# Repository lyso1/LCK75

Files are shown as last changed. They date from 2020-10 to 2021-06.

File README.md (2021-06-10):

# LCK75

a 75% through-hole keyboard designed by myself with inspiration from the CFTKB Discipline and Yiancar Gingham

LCK75-Mainboard

LCK75-Plate

LCK75-Bottom

<br />This work is licensed under a <a rel="license" href="http://creativecommons.org/licenses/by/4.0/">Creative Commons Attribution 4.0 International License</a>.

i will not be held responsible for your endeavors with private runs of this board. 

if you have questions reach out to me on discord @Lysol#5640

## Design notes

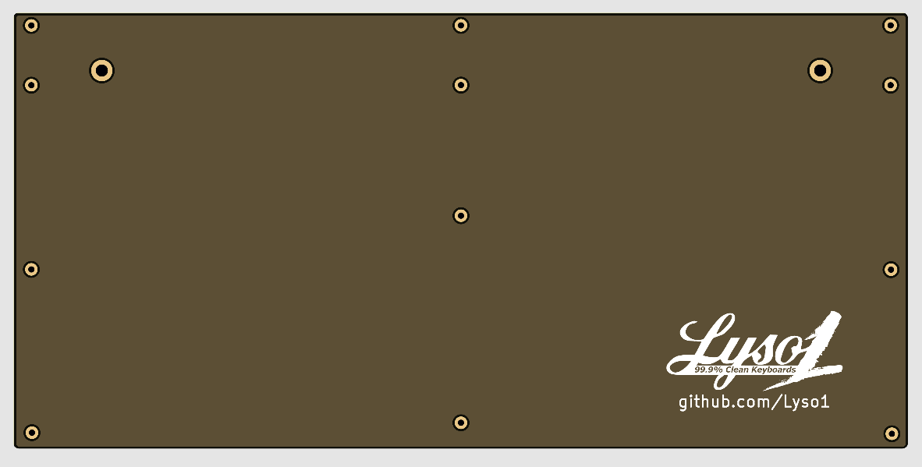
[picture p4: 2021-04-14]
LCK75 images/lck pcb designs - Imgur (2).png

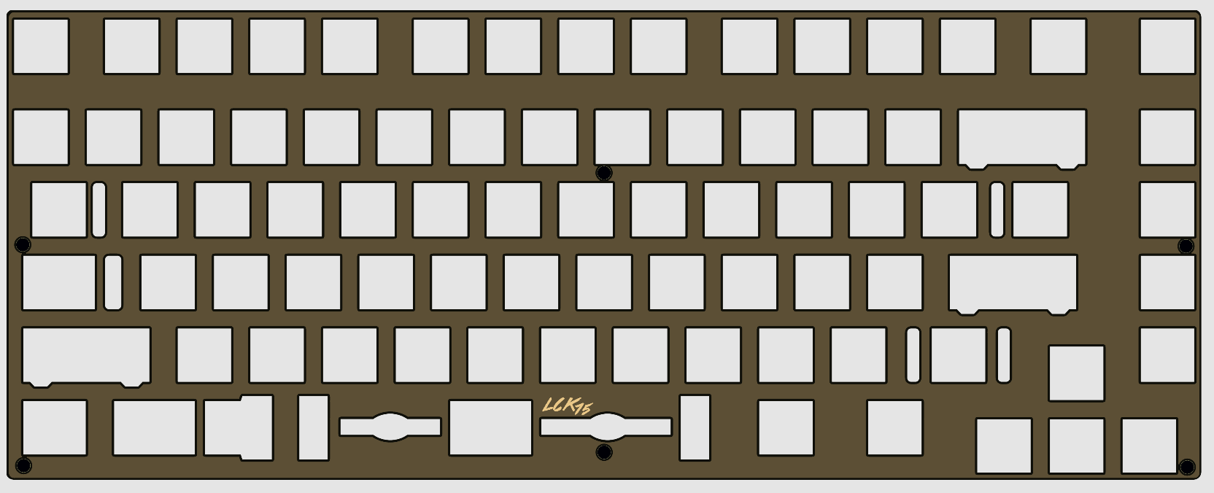
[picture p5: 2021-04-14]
LCK75 images/lck pcb designs - Imgur.png

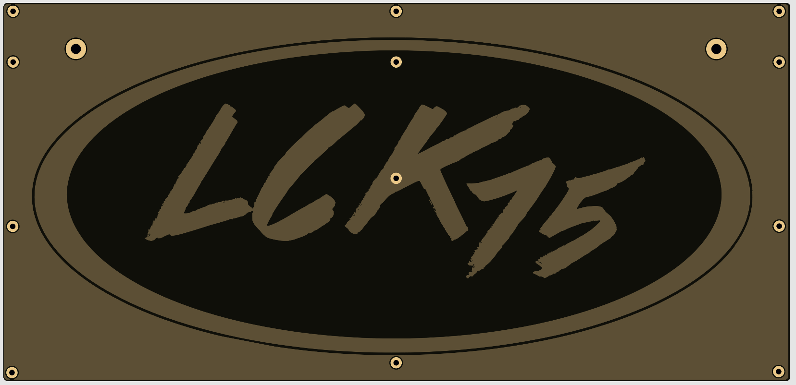
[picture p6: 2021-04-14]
LCK75 images/lck pcb designs - Imgur (1).png

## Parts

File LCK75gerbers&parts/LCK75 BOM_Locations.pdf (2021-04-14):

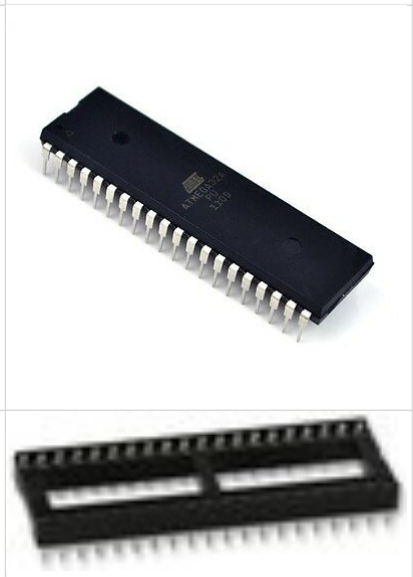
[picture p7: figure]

Location | Component
U1 | ATMEGA32A-PU

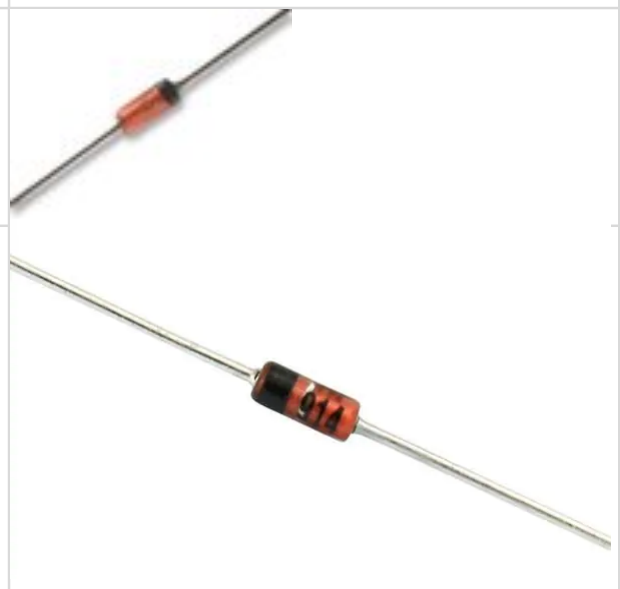
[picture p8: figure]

U1 | IC Socket
D1-D82 | through hole diodes/ 512-1N4148TR
Z1,Z2 | 3.6v Zener diodes

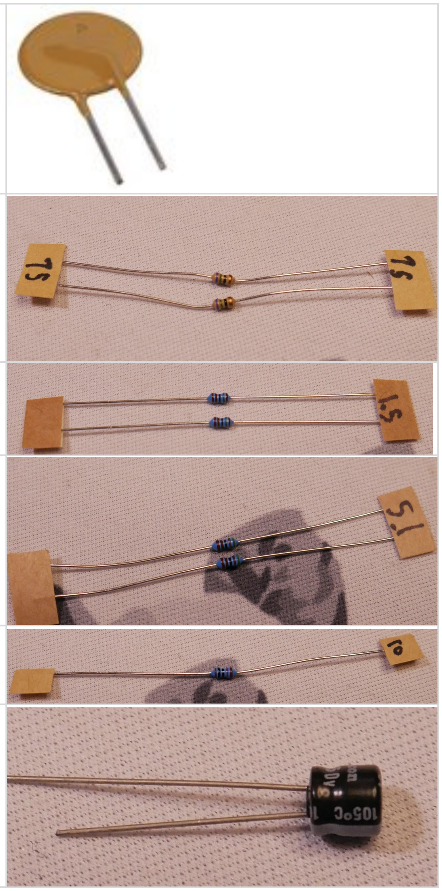
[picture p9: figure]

FUSE | 500mA fuse
R3,R4 | 75 ohm resistor
R1,R7 | 1.5k ohm resistor
R2,R5 | 5.1k ohm resistor
R6 | 10k ohm resistor
4.7uF | 4.7uF cylindrical capacitor

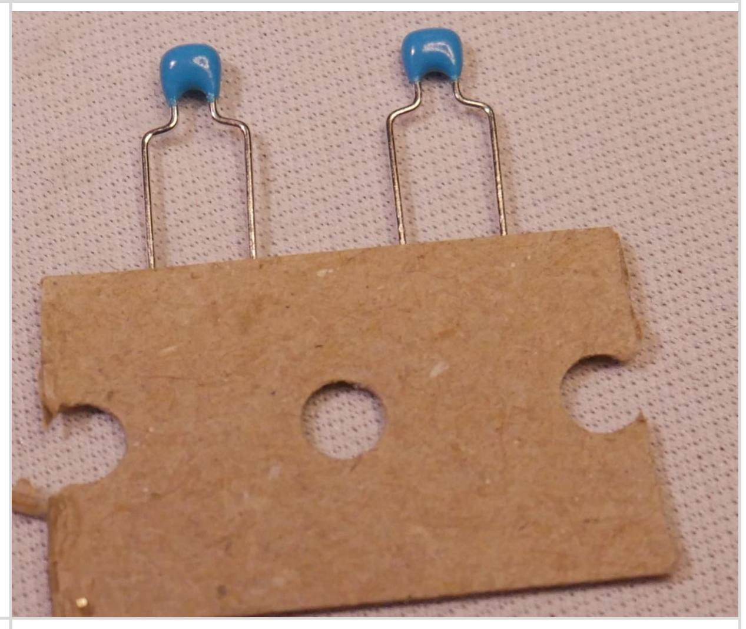
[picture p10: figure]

0.1uF | capacitors that go next to the microcontroller

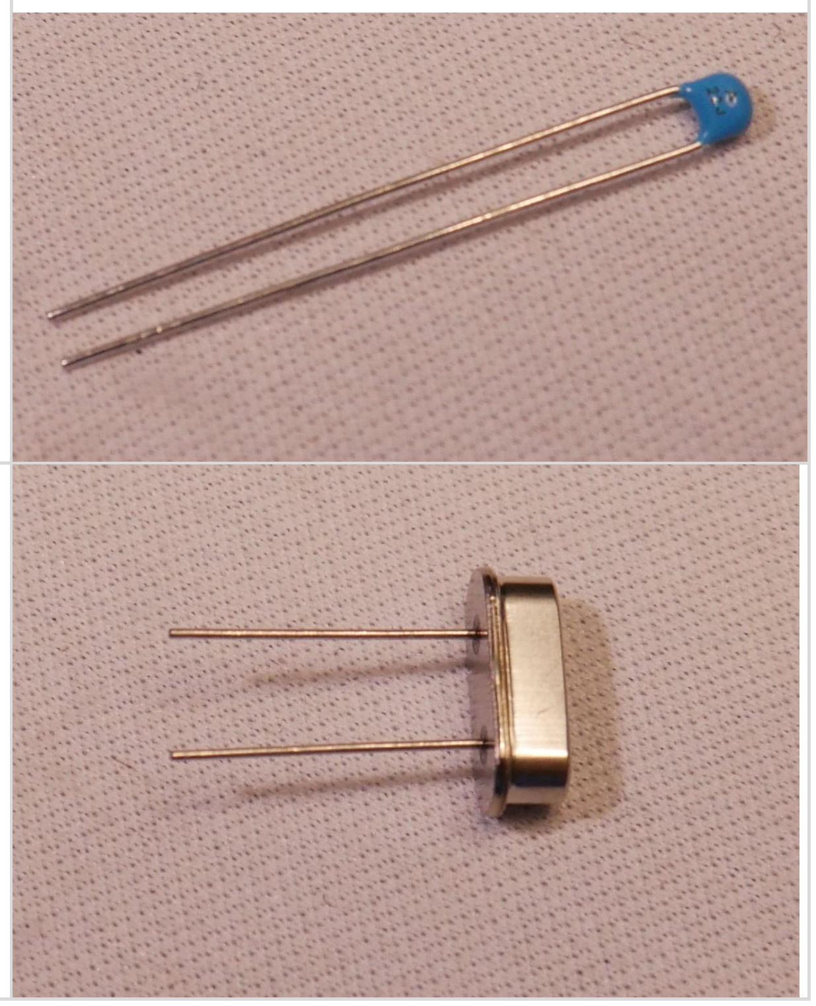
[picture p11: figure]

22pF | capacitors that goes between the crystal on the mainboard
Y1 | Crystal

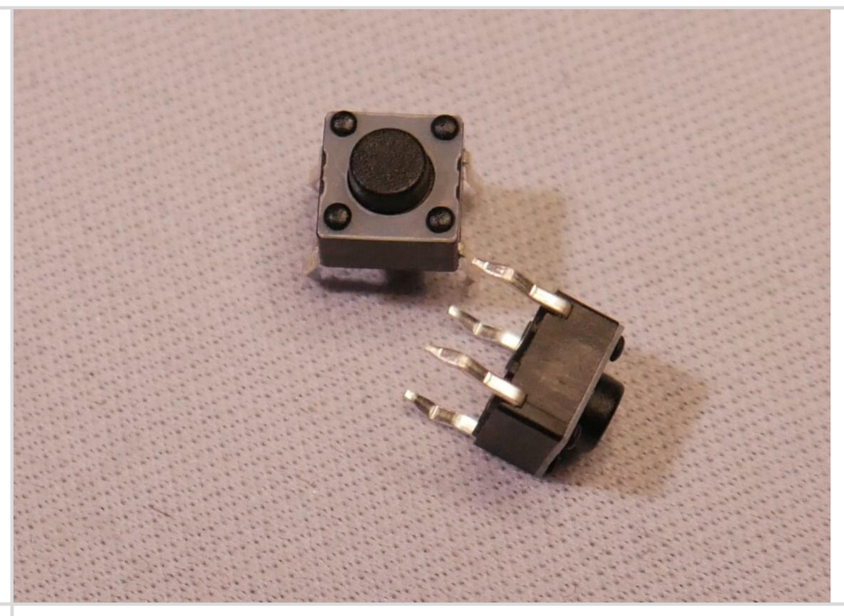
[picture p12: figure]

BOOT,RESET | 6mm push button
SW93 | Rotary Encoder
SSD1306 | OLED Screen
LED | LED
USB1 | USB C Connector

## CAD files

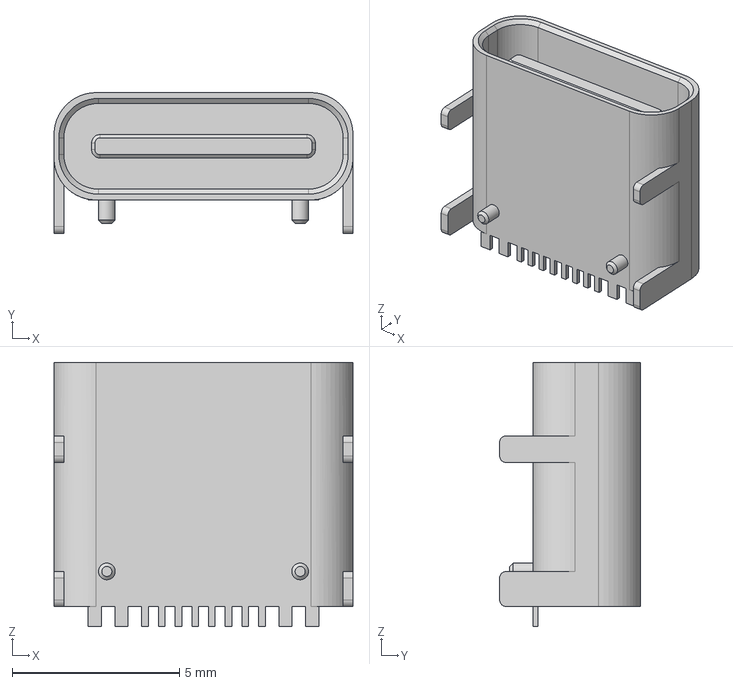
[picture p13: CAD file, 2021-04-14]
LCK75 kicad libs/Type-C.pretty-master/Type-C.pretty-master/HRO TYPE-C-31-M-12.step
8.94 x 4.21 x 7.90 mm

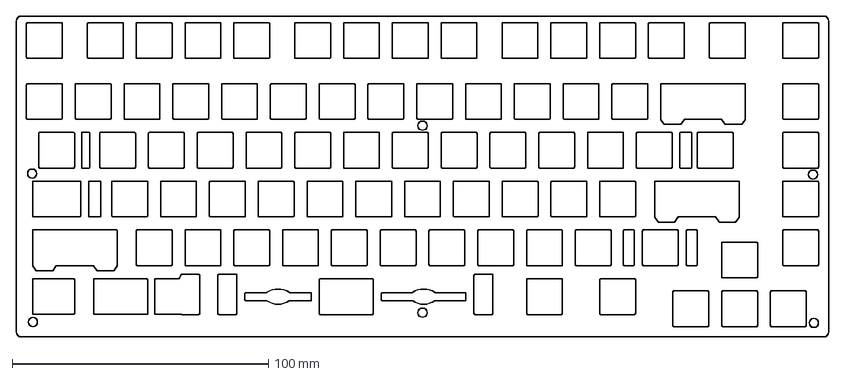
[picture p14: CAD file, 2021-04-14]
LCK75gerbers&parts/LCK75PLATE/LCK75-KITPLATErev1.dxf
317.3 x 125.3 mm

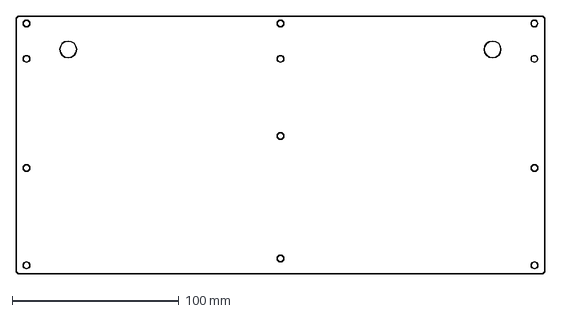
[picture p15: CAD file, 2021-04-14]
LCK75gerbers&parts/LCKFOAM&GUARD/LCKFOAM.dxf
317.3 x 154.8 mm

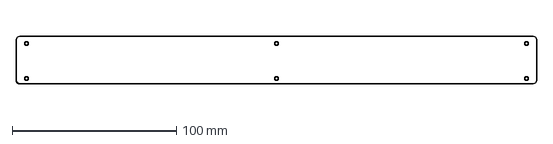
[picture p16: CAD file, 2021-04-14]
LCK75gerbers&parts/LCKFOAM&GUARD/LCK75-acrylic-guard.dxf
317.2 x 28.9 mm

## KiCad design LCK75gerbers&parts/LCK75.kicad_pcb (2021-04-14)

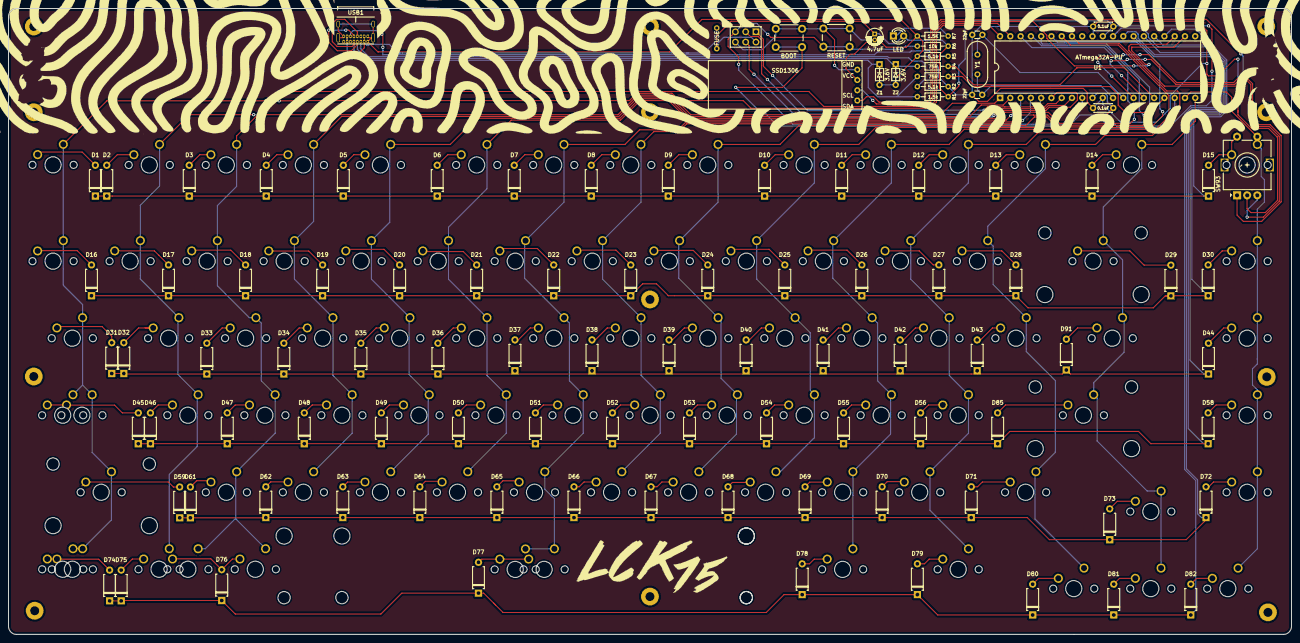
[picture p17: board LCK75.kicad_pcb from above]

Board: 2 copper layers, 317.3 x 154.8 mm, 192 parts (1 on the bottom side), 124 nets.

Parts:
C1, C2: 22pF; C_Disc_D3.0mm_W1.6mm_P2.50mm
C3: 4.7uF; CP_Radial_D4.0mm_P1.50mm
C4, C5: 0.1uF; C_Disc_D4.3mm_W1.9mm_P5.00mm
D1, D2, D3, D4, D5, D6, D7, D8, D9, D10, D11, D12, D13, D14, D15, D16, D17, D18, D19, D20, D21, D22, D23, D24, D25, D26, D27, D28, D29, D30, D31, D32, D33, D34, D35, D36, D37, D38, D39, D40, D41, D42, D43, D44, D45, D46, D47, D48, D49, D50, D51, D52, D53, D54, D55, D56, D58, D59, D61, D62, D63, D64, D65, D66, D67, D68, D69, D70, D71, D72, D73, D74, D75, D76, D77, D78, D79, D80, D81, D82, D85, D91: 1N4148; D_A-405_P7.62mm_Horizontal
F1: 500mA; polyfuse_5.1mm
J1: AVR-ISP-6; AVR_ICSP_3x2
LED: POWER; LED_D3.0mm
R1: 1.5k; R_Axial_DIN0204_L3.6mm_D1.6mm_P7.62mm_Horizontal
R2, R5: 5.1k; R_Axial_DIN0204_L3.6mm_D1.6mm_P7.62mm_Horizontal
R3, R4: 75R; R_Axial_DIN0204_L3.6mm_D1.6mm_P7.62mm_Horizontal
R6: 10k; R_Axial_DIN0204_L3.6mm_D1.6mm_P7.62mm_Horizontal
R7: 1.5K; R_Axial_DIN0204_L3.6mm_D1.6mm_P7.62mm_Horizontal
SSD1306: OLED; ssd1306 128x32 oled
SW1, SW2, SW3, SW4, SW5, SW6, SW7, SW8, SW9, SW10, SW11, SW12, SW13, SW14, SW15, SW16, SW17, SW18, SW19, SW20, SW21, SW22, SW23, SW24, SW25, SW26, SW27, SW28, SW30, SW32, SW33, SW34, SW35, SW36, SW37, SW38, SW39, SW40, SW41, SW42, SW43, SW45, SW46, SW48, SW49, SW50, SW51, SW52, SW53, SW54, SW55, SW56, SW57, SW58, SW61, SW65, SW66, SW67, SW68, SW69, SW70, SW71, SW72, SW73, SW74, SW76, SW77, SW84, SW85, SW86: SW_SPST; MXOnly-1U-NoLED
SW29: SW_SPST; MXOnly-2U-NoLED
SW31, SW44, SW82, SW83, SW88, SW89: SW_SPST; MXOnly-1.5U-NoLED
SW47, SW75: SW_SPST; MXOnly-1.75U-NoLED
SW60, SW63: SW_SPST; MXOnly-2.25U-NoLED
SW78, SW79, SW80: SW_SPST; MXOnly-1.25U-NoLED
SW81: SW_SPST; MXOnly-7U-ReversedStabilizers-NoLED
SW87, SW91: SW_PUSH-keyboard_parts; SW_PUSH_6mm
SW90: SW_SPST; MXOnly-6.25U-ReversedStabilizers-NoLED
SW93: Rotary_Encoder_Switch; RotaryEncoder_Alps_EC11E-Switch_Vertical_H20mm-new
U1: ATmega32A-PU; DIP-40_W15.24mm
USB1: Type-C_USB_C_GCT_USB4085; USB_C_GCT_USB4085
Y1: Crystal; Crystal_HC49-4H_Vertical
Z1, Z2: 3.6V; D_DO-35_SOD27_P5.08mm_Horizontal

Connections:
D+: R4.1, U1.16
D-: R3.1, U1.17
EC11-A: SW93.A, U1.14
EC11-B: SW93.B, U1.15
EC11-GND: C1.2, C2.2, C3.2, C4.2, C5.2, J1.6, R2.1, R5.2, R7.2, SSD1306.4, SW87.1, SW91.1, SW93.C, U1.11, U1.31, USB1.A1, USB1.B1, USB1.B12, USB1.S1, Z1.2, Z2.2
MISO: J1.1, U1.7
MOSI: J1.4, U1.6
unnamed: C1.1, U1.13, Y1.1
unnamed: C2.1, U1.12, Y1.2
unnamed: D1.2, SW1.1
unnamed: D2.2, SW2.1
unnamed: D3.2, SW3.1
unnamed: D4.2, SW4.1
unnamed: D5.2, SW5.1
unnamed: D6.2, SW6.1
unnamed: D7.2, SW7.1
unnamed: D8.2, SW8.1
unnamed: D9.2, SW9.1
unnamed: D10.2, SW10.1
unnamed: D11.2, SW11.1
unnamed: D12.2, SW12.1
unnamed: D13.2, SW13.1
unnamed: D14.2, SW14.1
unnamed: D15.2, SW15.1, SW93.S2
unnamed: D16.2, SW16.1
unnamed: D17.2, SW17.1
unnamed: D18.2, SW18.1
unnamed: D19.2, SW19.1
unnamed: D20.2, SW20.1
unnamed: D21.2, SW21.1
unnamed: D22.2, SW22.1
unnamed: D23.2, SW23.1
unnamed: D24.2, SW24.1
unnamed: D25.2, SW25.1
unnamed: D26.2, SW26.1
unnamed: D27.2, SW27.1
unnamed: D28.2, SW28.1
unnamed: D29.2, SW29.1
unnamed: D30.2, SW30.1
unnamed: D31.2, SW31.1
unnamed: D32.2, SW32.1
unnamed: D33.2, SW33.1
unnamed: D34.2, SW34.1
unnamed: D35.2, SW35.1
unnamed: D36.2, SW36.1
unnamed: D37.2, SW37.1
unnamed: D38.2, SW38.1
unnamed: D39.2, SW39.1
unnamed: D40.2, SW40.1
unnamed: D41.2, SW41.1
unnamed: D42.2, SW42.1
unnamed: D43.2, SW43.1
unnamed: D44.2, SW45.1
unnamed: D45.2, SW46.1, SW47.1
unnamed: D46.2, SW48.1
unnamed: D47.2, SW49.1
unnamed: D48.2, SW50.1
unnamed: D49.2, SW51.1
unnamed: D50.2, SW52.1
unnamed: D51.2, SW53.1
unnamed: D52.2, SW54.1
unnamed: D53.2, SW55.1
unnamed: D54.2, SW56.1
unnamed: D55.2, SW57.1
unnamed: D56.2, SW58.1
unnamed: D58.2, SW61.1
unnamed: D59.2, SW63.1
unnamed: D61.2, SW65.1
unnamed: D62.2, SW66.1
unnamed: D63.2, SW67.1
unnamed: D64.2, SW68.1
unnamed: D65.2, SW69.1
unnamed: D66.2, SW70.1
unnamed: D67.2, SW71.1
unnamed: D68.2, SW72.1
unnamed: D69.2, SW73.1
unnamed: D70.2, SW74.1
unnamed: D71.2, SW75.1
unnamed: D72.2, SW76.1
unnamed: D73.2, SW77.1
unnamed: D74.2, SW78.1, SW88.1
unnamed: D75.2, SW79.1
unnamed: D76.2, SW80.1, SW89.1
unnamed: D77.2, SW81.1, SW90.1
unnamed: D78.2, SW82.1
unnamed: D79.2, SW83.1
unnamed: D80.2, SW84.1
unnamed: D81.2, SW85.1
unnamed: D82.2, SW86.1
unnamed: R1.2, R3.2, USB1.A7, USB1.B7, Z1.1
unnamed: R4.2, USB1.A6, USB1.B6, Z2.1
unnamed: D85.2, SW60.1
unnamed: D91.2, SW44.1
unnamed: LED.1, R7.1
unnamed: R2.2, USB1.A5
unnamed: R5.1, USB1.B5
SCK: J1.3, U1.8
VCC: F1.2, USB1.A4, USB1.A9, USB1.B4, USB1.B9
boot: SW87.2, U1.18
col0: SW1.2, SW16.2, SW31.2, SW46.2, SW47.2, SW63.2, SW78.2, SW88.2, U1.40
col1: SW2.2, SW17.2, SW32.2, SW48.2, SW79.2, U1.1
col2: SW3.2, SW18.2, SW33.2, SW49.2, SW65.2, SW80.2, SW89.2, U1.39
col3: SW4.2, SW19.2, SW34.2, SW50.2, SW66.2, U1.2
col4: SW5.2, SW20.2, SW35.2, SW51.2, SW67.2, U1.38
col5: SW6.2, SW21.2, SW36.2, SW52.2, SW68.2, U1.3
col6: SW7.2, SW22.2, SW37.2, SW53.2, SW69.2, SW81.2, SW90.2, U1.37
col7: SW8.2, SW23.2, SW38.2, SW54.2, SW70.2, U1.4
col8: SW9.2, SW24.2, SW39.2, SW55.2, SW71.2, U1.36
col9: SW10.2, SW25.2, SW40.2, SW56.2, SW72.2, U1.5
col10: SW11.2, SW26.2, SW41.2, SW57.2, SW73.2, SW82.2, U1.35
col11: SW12.2, SW27.2, SW42.2, SW58.2, SW74.2, SW83.2, U1.34
col12: SW13.2, SW28.2, SW43.2, SW75.2, SW84.2, U1.33
col13: SW14.2, SW29.2, SW44.2, SW60.2, SW77.2, SW85.2, U1.20
col14: SW15.2, SW30.2, SW45.2, SW61.2, SW76.2, SW86.2, SW93.S1, U1.19
oledSCL: SSD1306.2, U1.22
oledSDA: SSD1306.1, U1.23
oledVCC: C3.1, C4.1, C5.1, F1.1, J1.2, LED.2, R1.1, R6.1, SSD1306.3, U1.10, U1.30
reset: J1.5, R6.2, SW91.2, U1.9
row0: D1.1, D2.1, D3.1, D4.1, D5.1, D6.1, D7.1, D8.1, D9.1, D10.1, D11.1, D12.1, D13.1, D14.1, D15.1, U1.24
row1: D16.1, D17.1, D18.1, D19.1, D20.1, D21.1, D22.1, D23.1, D24.1, D25.1, D26.1, D27.1, D28.1, D29.1, D30.1, U1.25
row2: D31.1, D32.1, D33.1, D34.1, D35.1, D36.1, D37.1, D38.1, D39.1, D40.1, D41.1, D42.1, D43.1, D44.1, D91.1, U1.29
row3: D45.1, D46.1, D47.1, D48.1, D49.1, D50.1, D51.1, D52.1, D53.1, D54.1, D55.1, D56.1, D58.1, D85.1, U1.26
row4: D59.1, D61.1, D62.1, D63.1, D64.1, D65.1, D66.1, D67.1, D68.1, D69.1, D70.1, D71.1, D72.1, D73.1, U1.28
row5: D74.1, D75.1, D76.1, D77.1, D78.1, D79.1, D80.1, D81.1, D82.1, U1.27

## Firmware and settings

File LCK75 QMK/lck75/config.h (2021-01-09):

/*Copyright 2019 Lyso1

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
You should have received a copy of the GNU General Public License
along with this program.  If not, see <http://www.gnu.org/licenses/>.
*/

#pragma once

#include "config_common.h"

#define VENDOR_ID       0x2703
#define PRODUCT_ID      0x37FJ
#define DEVICE_VER      0x0001
#define MANUFACTURER    Lyso1
#define PRODUCT         lck75
#define DESCRIPTION     75% keyboard that can be assembled with only through hole components

/* key matrix size */
#define MATRIX_ROWS 6
#define MATRIX_COLS 15

/*
 * Keyboard Matrix Assignments
 *
 * Change this to how you wired your keyboard
 * COLS: AVR pins used for columns, left to right
 * ROWS: AVR pins used for rows, top to bottom
 * DIODE_DIRECTION: COL2ROW = COL = Anode (+), ROW = Cathode (-, marked on diode)
 *                  ROW2COL = ROW = Anode (+), COL = Cathode (-, marked on diode)
 *
 */
/*                        0    1    2    3    4    5    6    7    8    9   10  11  12  13  14*/
#define MATRIX_ROW_PINS { C2, C3, C7, C4, C6, C5 }
#define MATRIX_COL_PINS { A0, B0, A1, B1, A2, B2, A3, B3, A4, B4, A5, A6, A7, D6, D5 }
#define UNUSED_PINS

#define ENCODERS_PAD_B { D1 }
#define ENCODERS_PAD_A { D0 }
#define ENCODER_RESOLUTION 2 //default/suggested

/* COL2ROW, ROW2COL*/
#define DIODE_DIRECTION COL2ROW

/* Debounce reduces chatter (unintended double-presses) - set 0 if debouncing is not needed */
#define DEBOUNCE 5

/* Mechanical locking support. Use KC_LCAP, KC_LNUM or KC_LSCR instead in keymap */
#define LOCKING_SUPPORT_ENABLE
/* Locking resynchronize hack */
#define LOCKING_RESYNC_ENABLE

#define SSD1306OLED

/* Bootmagic Lite key configuration */
#define BOOTMAGIC_LITE_ROW 0
#define BOOTMAGIC_LITE_COLUMN 0

#define RGBLIGHT_SLEEP

#define OLED_TIMEOUT 10000

#define UNICODE_SELECTED_MODES UC_WINC, UC_MAC, UC_LNX

#define UNICODE_CYCLE_PERSIST false

/* #define AUTO_SHIFT_MODIFIERS */
/* #define AUTO_SHIFT_TIMEOUT 170 */
/* #define NO_AUTO_SHIFT_SPECIAL */
/* #define NO_AUTO_SHIFT_NUMERIC */

#ifdef LOCKING_SUPPORT_ENABLE
#    undef LOCKING_SUPPORT_ENABLE
#endif
#ifdef LOCKING_RESYNC_ENABLE
#    undef LOCKING_RESYNC_ENABLE
#endif

#ifndef NO_DEBUG
#define NO_DEBUG
#endif


#if !defined(NO_PRINT) && !defined(CONSOLE_ENABLE)
#define NO_PRINT
#endif

#define OLED_FONT_H "keyboards/lck75/glcdfont.c"

#define IGNORE_MOD_TAP_INTERRUPT
#define PERMISSIVE_HOLD
#define TAPPING_TERM 200

#define NO_ACTION_ONESHOT

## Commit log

2020-10-01 added some of the pcb design parts
    [LCK75-B_Cu.gbr, LCK75-B_Mask.gbr, LCK75-B_Paste.gbr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]
2021-04-14 updated for rev 1 productions files
    [LCK75-B_Cu.gbr, LCK75-B_Mask.gbr, LCK75-B_Paste.gbr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]
2021-04-14 renamed files
    [LCK75-B_Cu.gbr, LCK75-B_Mask.gbr, LCK75-B_Paste.gbr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]
2021-04-14 add images
    [HRO TYPE-C-31-M-12.step]
2021-06-10 missing files i forgot
    [LCK75.sch]

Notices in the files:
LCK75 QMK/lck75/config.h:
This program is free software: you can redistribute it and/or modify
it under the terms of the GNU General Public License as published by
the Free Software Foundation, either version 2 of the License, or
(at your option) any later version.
